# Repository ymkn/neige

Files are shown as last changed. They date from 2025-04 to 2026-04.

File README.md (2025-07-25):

# Neige

A compact 3-rows 30% keyboard with 12-column row staggered layout in 12.75u width.

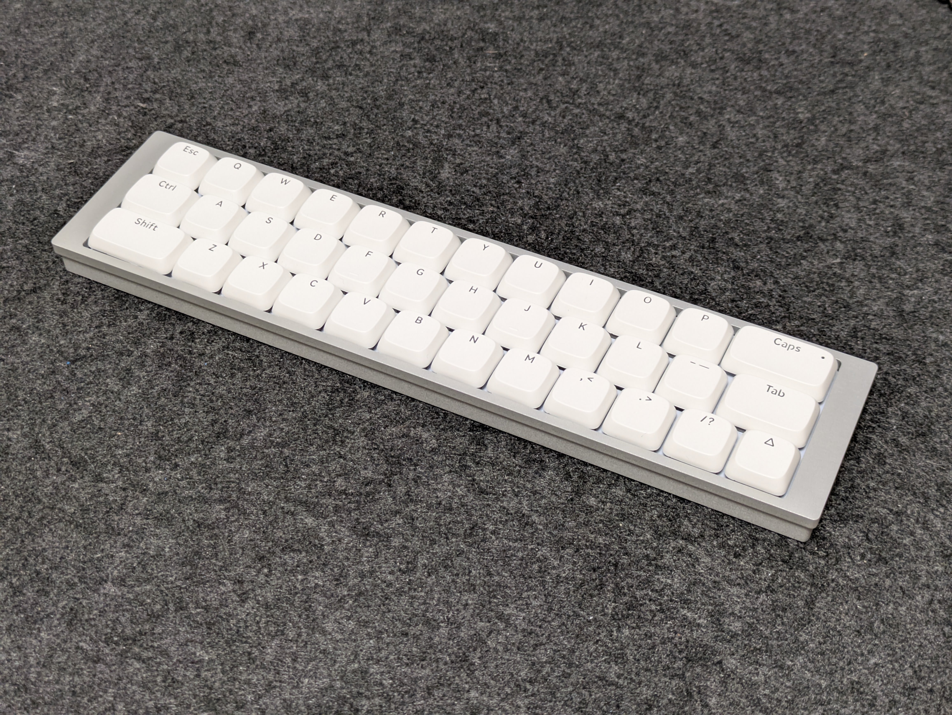
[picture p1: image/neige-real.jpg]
Neige real image


## Default Layout

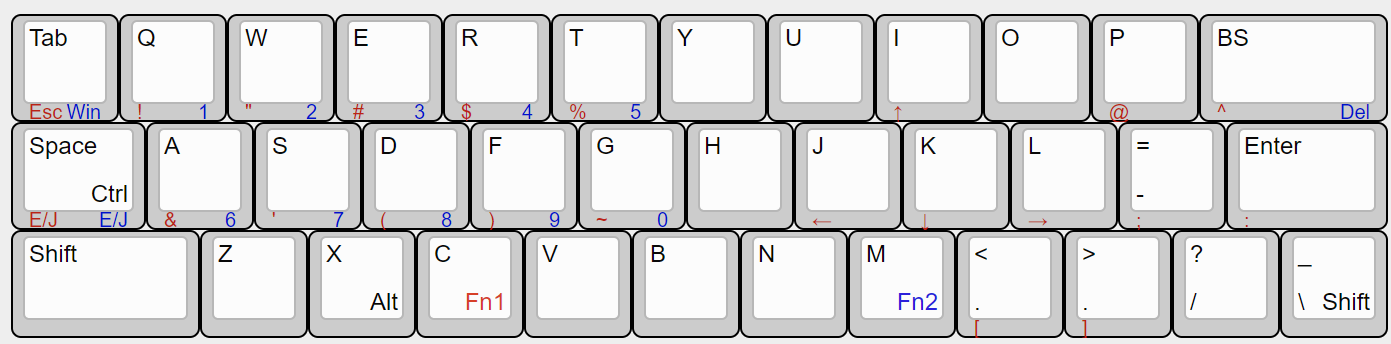
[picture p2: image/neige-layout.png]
Neige layouts


You can also customize the layout using [Vial](https://get.vial.today/).

## Build Guide

See [Build Guide](https://ymkn.github.io/buildguide/neige.html).

## License

This project is licensed under the MIT License, see the [LICENSE file](LICENSE) for details.

However, this does not apply to logo data (image files, KiCAD footprints, etc.) included in the resources of this project.

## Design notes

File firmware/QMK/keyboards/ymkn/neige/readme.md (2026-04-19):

# neige

neige - A compact 30% keyboard with 3-rows and 12-columns row staggered layout in 12.75u width.

* Keyboard Maintainer: [ymkn](https://github.com/ymkn)

Make example for this keyboard (after setting up your build environment):

    make ymkn/neige:vial

Flashing example for this keyboard:

1. Install and open [QMK Toolbox](https://qmk.fm/toolbox).
2. Disconnect the keyboard from the computer.
3. Hold the top-left key while connecting the USB cable, or hold the BOOT button on the back of the PCB while connecting the USB cable.
4. Confirm that QMK Toolbox shows `STM32 DFU device connected (WinUSB): STMicroelectronics STM32 BOOTLOADER`.
5. Click `Open` and select the compiled firmware file.
6. Click `Flash` and wait for the process to finish.
7. When QMK Toolbox shows `Flash complete`, the firmware update is complete.

This keyboard supports [Vial](https://get.vial.today/) configurator.

## Bootloader

Enter the bootloader in 2 ways:

* **Key on plug-in**: Hold the top-left key while connecting the keyboard to USB.
* **BOOT button**: Hold the BOOT button on the back of the PCB while connecting the keyboard to USB.

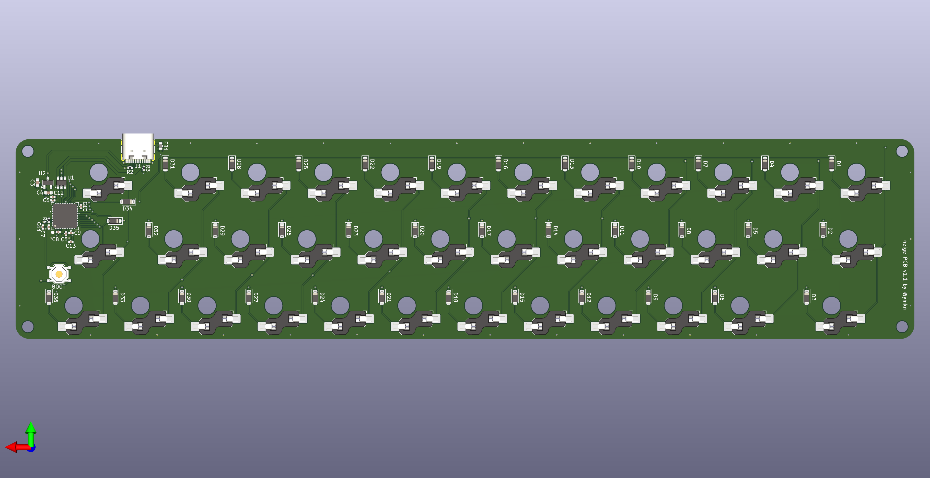
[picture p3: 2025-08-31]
KiCAD/PCB/production/Neige_PCB.png

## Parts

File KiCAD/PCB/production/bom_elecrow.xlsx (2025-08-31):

*Reference | *Manufacturer Part number | *QTY | *Original | Description | Purchase Link
BTN_BOOT1 | TS-1187A-B-A-B | 1 | N | No Without Bracket 50mA 5.1mm 100,000 Cycles 1.6N 12V 5.1mm 1.5mm Round Button Surface Mount,Vertical SPST SMD Tactile Switches ROHS | https://lcsc.com/product-detail/Tactile-Switches_XKB-Connectivity-TS-1187A-B-A-B_C318884.html
C9 | CL05B103KB5NNNC | 1 | N | 10nF 50V X7R ±10% 0402 Multilayer Ceramic Capacitors MLCC - SMD/SMT ROHS | https://lcsc.com/product-detail/Multilayer-Ceramic-Capacitors-MLCC-SMD-SMT_Samsung-Electro-Mechanics-CL05B103KB5NNNC_C15195.html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
C10, C5, C6, C7, C8 | CL05B104KO5NNNC | 6 | N | 16V 100nF X7R ±10% 0402 Multilayer Ceramic Capacitors MLCC - SMD/SMT ROHS | https://lcsc.com/product-detail/Multilayer-Ceramic-Capacitors-MLCC-SMD-SMT_Samsung-Electro-Mechanics-CL05B104KO5NNNC_C1525.html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
C3, C4 | CL10A106KP8NNNC | 2 | N | 10V 10uF X5R ±10% 0603 Multilayer Ceramic Capacitors MLCC - SMD/SMT ROHS | https://lcsc.com/product-detail/Multilayer-Ceramic-Capacitors-MLCC-SMD-SMT_Samsung-Electro-Mechanics-CL10A106KP8NNNC_C19702.html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
C11, C12 | CL05A475MP5NRNC | 2 | N | 10V 4.7uF X5R ±20% 0402 Multilayer Ceramic Capacitors MLCC - SMD/SMT ROHS | https://lcsc.com/product-detail/Multilayer-Ceramic-Capacitors-MLCC-SMD-SMT_Samsung-Electro-Mechanics-CL05A475MP5NRNC_C23733.html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
C13 | CL05A105KA5NQNC | 1 | N | 25V 1uF X5R ±10% 0402 Multilayer Ceramic Capacitors MLCC - SMD/SMT ROHS | https://lcsc.com/product-detail/Multilayer-Ceramic-Capacitors-MLCC-SMD-SMT_Samsung-Electro-Mechanics-CL05A105KA5NQNC_C52923.html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
D1 - D36 | 1N4148W | 36 | N | 75V Independent 1V@50mA 4ns 150mA SOD-123 Switching Diodes ROHS | https://lcsc.com/product-detail/Switching-Diodes_ST-Semtech-1N4148W_C81598.html?s_z=n_C81598
FB1 | CBM160808U600T | 1 | N | ±25% 60Ω@100MHz 0603 Ferrite Beads ROHS | https://lcsc.com/product-detail/Ferrite-Beads_FH-Guangdong-Fenghua-Advanced-Tech-CBM160808U600T_C394426.html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
J1 | TYPE-C 16PIN 2MD(073) | 1 | N | 3A USB 3.1 1 Surface Mount, Right Angle 16P Female -25℃~+85℃ Type-C SMD USB Connectors ROHS | https://lcsc.com/product-detail/USB-Connectors_SHOU-HAN-TYPE-C-16PIN-2MD-3_C2765186.html?s_z=n_C2765186
R2, R3 | 0402WGF5101TCE | 2 | N | 62.5mW Thick Film Resistor 50V ±100ppm/℃ ±1% 5.1kΩ 0402 Chip Resistor - Surface Mount ROHS | https://lcsc.com/product-detail/Chip-Resistor-Surface-Mount_UNI-ROYAL-Uniroyal-Elec-0402WGF5101TCE_C25905.html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
R4 | 0402WGF1002TCE | 1 | N | 62.5mW Thick Film Resistor 50V ±100ppm/℃ ±1% 10kΩ 0402 Chip Resistor - Surface Mount ROHS | https://lcsc.com/product-detail/Chip-Resistor-Surface-Mount_UNI-ROYAL-Uniroyal-Elec-0402WGF1002TCE_C25744.html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
SW1 - SW36 | CPG135001S30 | 36 | N | SMD Mechanical Keyboard Shaft ROHS | https://www.kailhswitch.com/mechanical-keyboard-switches/box-switches/choc-type-hot-swap-socket.html
U1 | USBLC6-2SC6 | 1 | N | 5A 17V 6V Unidirectional 5.25V SOT-23-6 ESD and Surge Protection (TVS/ESD) ROHS | https://lcsc.com/product-detail/ESD-and-Surge-Protection-TVS-ESD_STMicroelectronics-USBLC6-2SC6_C7519.html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
U2 | XC6206P332MR-G | 1 | N | 200mA Fixed 3.3V Positive 6V SOT-23-3L Voltage Regulators - Linear, Low Drop Out (LDO) Regulators ROHS | https://lcsc.com/product-detail/Voltage-Regulators-Linear-Low-Drop-Out-LDO-Regulators_Torex-Semicon-XC6206P332MR-G_C5446.html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
U3 | STM32F072CBU6 | 1 | Y | ARM-M0 48MHz UFQFPN-48(7x7) Microcontrollers (MCU/MPU/SOC) ROHS | https://lcsc.com/product-detail/Microcontrollers-MCU-MPU-SOC_STMicroelectronics-STM32F072CBU6_C92504.html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
Declare：
All ICs will be original even you selected Not original required.
Original: Y means must use the original brand model, N means that you can accept the substitutes with similar spec

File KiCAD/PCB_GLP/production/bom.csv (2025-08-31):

Designator | Footprint | Quantity | Value | LCSC Part #
BTN_BOOT1 | SW_Push_1P1T_XKB_TS-1187A | 1 | SW_Push | C318884
C10, C5, C6, C7, C8 | 0402 | 5 | 100nF | C1525
C11, C12 | 0402 | 2 | 4.7uF | C23733
C13 | 0402 | 1 | 1uF | C52923
C3, C4 | 0603 | 2 | 10uF | C19702
C9 | 0402 | 1 | 10nF | C15195
D1, D10, D11, D12, D13, D14, D15, D16, D17, D18, D19, D2, D20, D21, D22, D23, D24, D25, D26, D27, D28, D29, D3, D30, D31, D32, D33, D34, D35, D36, D4, D5, D6, D7, D8, D9 | D_SOD-123 | 36 | 1N4148W | C81598
FB1 | 0603 | 1 | FerriteBead | C394426
J1 | USB_C_Receptacle_HRO_TYPE-C-31-M-12 | 1 | TYPE-C 16PIN 2MD(073) | C2765186
R2, R3 | 0402 | 2 | 5.1K | C25905
R4 | 0402 | 1 | 10K | C25744
SW1, SW10, SW11, SW12, SW13, SW14, SW15, SW16, SW17, SW18, SW19, SW20, SW21, SW22, SW23, SW24, SW25, SW26, SW27, SW28, SW29, SW30, SW31, SW32, SW33, SW36, SW4, SW5, SW6, SW7, SW8, SW9 | SW_MX_GLP3_1u | 32 | SW_Push | C41430893
SW2 | SW_MX_GLP3_1.25u | 1 | SW_Push | C41430893
SW3, SW34 | SW_MX_GLP3_1.75u | 2 | SW_Push | C41430893
SW35 | SW_MX_GLP3_1.5u | 1 | SW_Push | C41430893
U1 | SOT-23-6 | 1 | USBLC6-2SC6 | C7519
U2 | SOT-23-3 | 1 | XC6206P332MR | C5446
U3 | UFQFPN48-7x7mm | 1 | STM32F072CBU6 | C92504

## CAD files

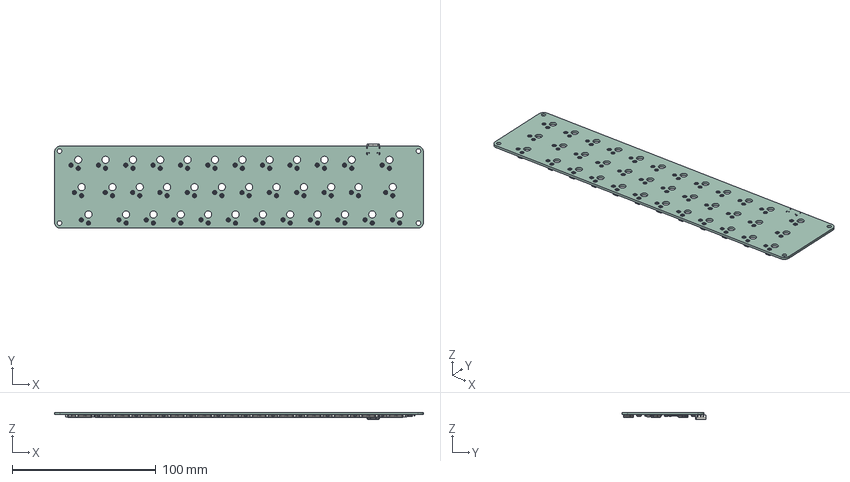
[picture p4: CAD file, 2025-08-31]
KiCAD/PCB/production/Neige_PCB.step
257.0 x 58.7 x 4.96 mm
HS_Kailh_Choc v4 x 36
D_SOD_123 x 36
R_0402_1005Metric x 3
C_0402_1005Metric x 9
L_0603_1608Metric
SOT-23-3
QFN-48-1EP_7x7mm_Pitch0.5mm
USB_C_Receptacle_16P_TopMnt_Horizontal_GCT_USB4105-xx-A
SOT_23_6
C_0603_1608Metric x 2
SW_SPST_TL3342
Neige_PCB_PCB

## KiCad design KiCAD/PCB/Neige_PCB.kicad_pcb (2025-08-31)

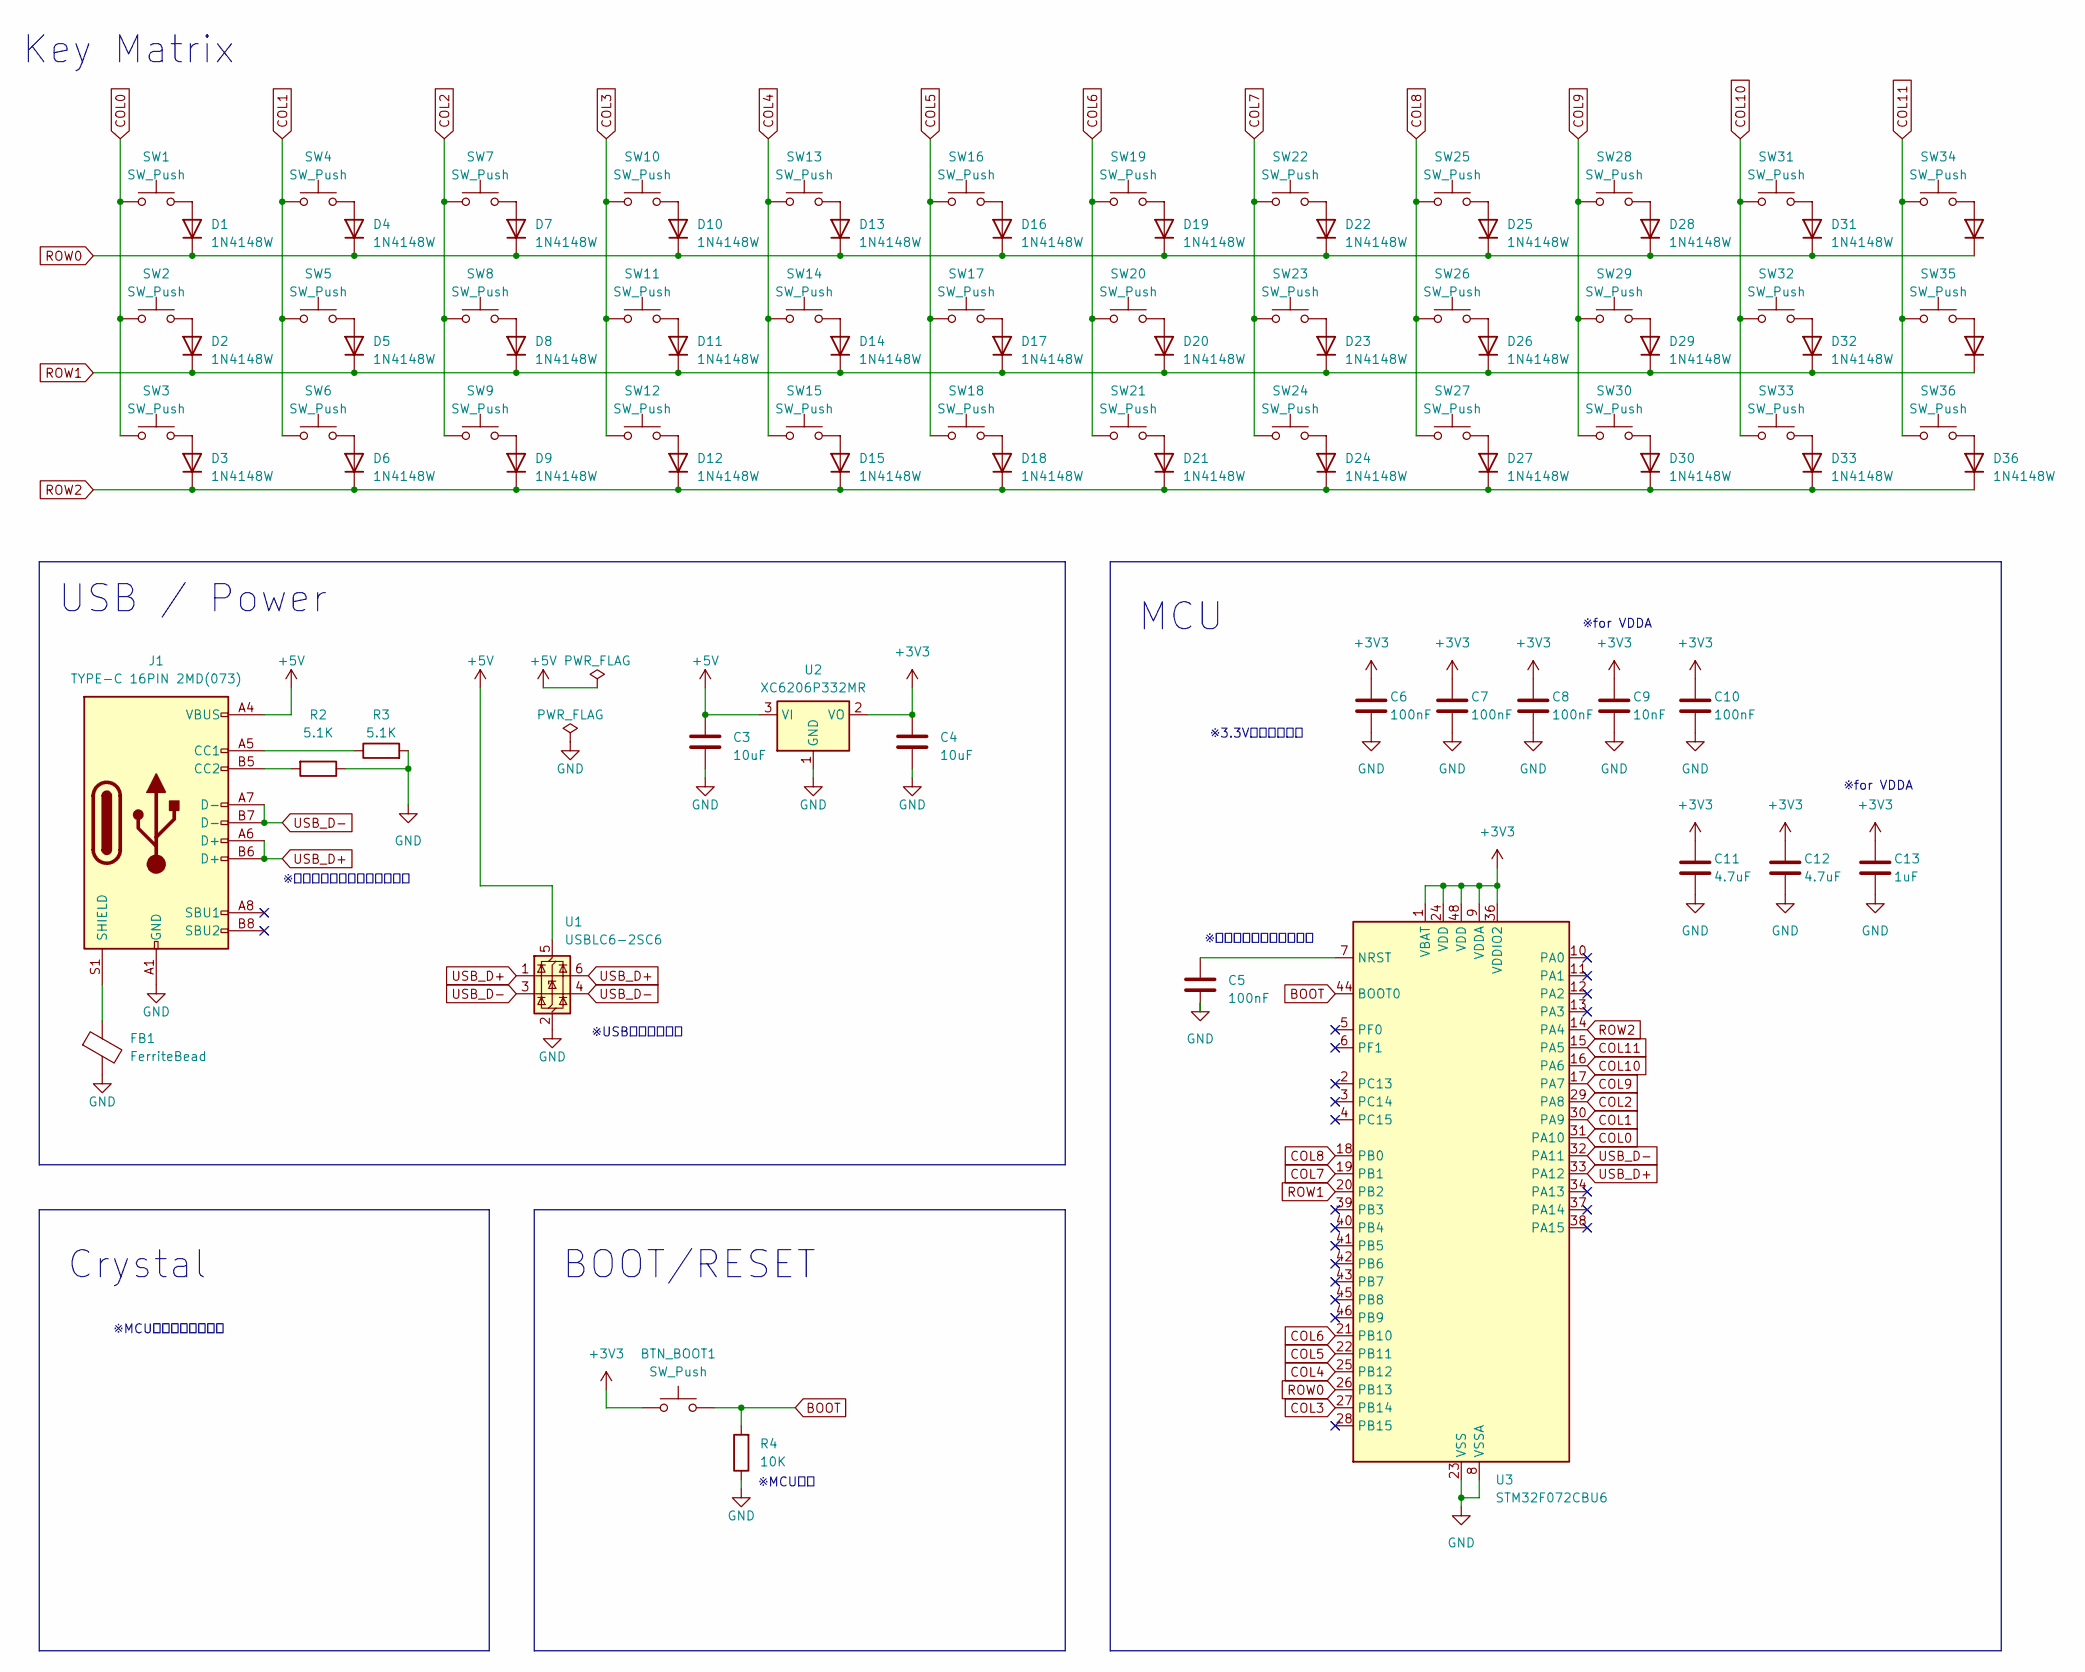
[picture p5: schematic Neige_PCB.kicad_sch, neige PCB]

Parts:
BTN_BOOT1: SW_Push; SW_Push_1P1T_XKB_TS-1187A; JLCPCB Part # C318884
C3, C4: 10uF; C_0603_1608Metric; JLCPCB Part # C19702
C5, C6, C7, C8, C10: 100nF; C_0402_1005Metric; JLCPCB Part # C1525
C9: 10nF; C_0402_1005Metric; JLCPCB Part # C15195
C11, C12: 4.7uF; C_0402_1005Metric; JLCPCB Part # C23733
C13: 1uF; C_0402_1005Metric; JLCPCB Part # C52923
D1, D2, D3, D4, D5, D6, D7, D8, D9, D10, D11, D12, D13, D14, D15, D16, D17, D18, D19, D20, D21, D22, D23, D24, D25, D26, D27, D28, D29, D30, D31, D32, D33, D34, D35, D36: 1N4148W; D_SOD-123; LCSC Parts # C81598
FB1: FerriteBead; L_0603_1608Metric; JLCPCB Part # C394426
J1: TYPE-C 16PIN 2MD(073); USB_C_Receptacle_HRO_TYPE-C-31-M-12; JLCPCB Part # C2765186
R2, R3: 5.1K; R_0402_1005Metric; JLCPCB Part # C25905
R4: 10K; R_0402_1005Metric; JLCPCB Part # C25744
SW1, SW4, SW5, SW6, SW7, SW8, SW9, SW10, SW11, SW12, SW13, SW14, SW15, SW16, SW17, SW18, SW19, SW20, SW21, SW22, SW23, SW24, SW25, SW26, SW27, SW28, SW29, SW30, SW31, SW32, SW33, SW36: SW_Push; SW_choc_v2_1u; LCSC Parts # C18212911
SW2: SW_Push; SW_choc_v2_1.25u; LCSC Parts # C18212911
SW3, SW34: SW_Push; SW_choc_v2_1.75u; LCSC Parts # C18212911
SW35: SW_Push; SW_choc_v2_1.5u; LCSC Parts # C18212911
U1: USBLC6-2SC6; SOT-23-6; JLCPCB Part # C7519
U2: XC6206P332MR; SOT-23-3; JLCPCB Part # C5446
U3: STM32F072CBU6; UFQFPN48-7x7mm; JLCPCB Part # C92504

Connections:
+3V3: BTN_BOOT1.1, C4.1, C6.1, C7.1, C8.1, C9.1, C10.1, C11.1, C12.1, C13.1, U2.2 (VO), U3.1 (VBAT), U3.9 (VDDA), U3.24 (VDD), U3.36 (VDDIO2), U3.48 (VDD)
+5V: C3.1, J1.A4 (VBUS), J1.A9 (VBUS), J1.B4 (VBUS), J1.B9 (VBUS), U1.5 (VBUS), U2.3 (VI)
BOOT: BTN_BOOT1.2, R4.2, U3.44 (BOOT0)
COL0: SW1.1, SW2.1, SW3.1, U3.31 (PA10)
COL1: SW4.1, SW5.1, SW6.1, U3.30 (PA9)
COL2: SW7.1, SW8.1, SW9.1, U3.29 (PA8)
COL3: SW10.1, SW11.1, SW12.1, U3.27 (PB14)
COL4: SW13.1, SW14.1, SW15.1, U3.25 (PB12)
COL5: SW16.1, SW17.1, SW18.1, U3.22 (PB11)
COL6: SW19.1, SW20.1, SW21.1, U3.21 (PB10)
COL7: SW22.1, SW23.1, SW24.1, U3.19 (PB1)
COL8: SW25.1, SW26.1, SW27.1, U3.18 (PB0)
COL9: SW28.1, SW29.1, SW30.1, U3.17 (PA7)
COL10: SW31.1, SW32.1, SW33.1, U3.16 (PA6)
COL11: SW34.1, SW35.1, SW36.1, U3.15 (PA5)
GND: C3.2, C4.2, C5.2, C6.2, C7.2, C8.2, C9.2, C10.2, C11.2, C12.2, C13.2, FB1.2, J1.A1 (GND), J1.A12 (GND), J1.B1 (GND), J1.B12 (GND), R2.1, R3.2, R4.1, U1.2 (GND), U2.1 (GND), U3.8 (VSSA), U3.23 (VSS), U3.35 (VSS), U3.47 (VSS), U3.49 (VSS)
unnamed: D1.2 (A), SW1.2
unnamed: D2.2 (A), SW2.2
unnamed: D3.2 (A), SW3.2
unnamed: D4.2 (A), SW4.2
unnamed: D5.2 (A), SW5.2
unnamed: D6.2 (A), SW6.2
unnamed: D7.2 (A), SW7.2
unnamed: D8.2 (A), SW8.2
unnamed: D9.2 (A), SW9.2
unnamed: D10.2 (A), SW10.2
unnamed: D11.2 (A), SW11.2
unnamed: D12.2 (A), SW12.2
unnamed: D13.2 (A), SW13.2
unnamed: D14.2 (A), SW14.2
unnamed: D15.2 (A), SW15.2
unnamed: D16.2 (A), SW16.2
unnamed: D17.2 (A), SW17.2
unnamed: D18.2 (A), SW18.2
unnamed: D19.2 (A), SW19.2
unnamed: D20.2 (A), SW20.2
unnamed: D21.2 (A), SW21.2
unnamed: D22.2 (A), SW22.2
unnamed: D23.2 (A), SW23.2
unnamed: D24.2 (A), SW24.2
unnamed: D25.2 (A), SW25.2
unnamed: D26.2 (A), SW26.2
unnamed: D27.2 (A), SW27.2
unnamed: D28.2 (A), SW28.2
unnamed: D29.2 (A), SW29.2
unnamed: D30.2 (A), SW30.2
unnamed: D31.2 (A), SW31.2
unnamed: D32.2 (A), SW32.2
unnamed: D33.2 (A), SW33.2
unnamed: D34.2 (A), SW34.2
unnamed: D35.2 (A), SW35.2
unnamed: D36.2 (A), SW36.2
unnamed: J1.A5 (CC1), R3.1
unnamed: J1.B5 (CC2), R2.2
unnamed: FB1.1, J1.S1 (SHIELD)
unnamed: C5.1, U3.7 (NRST)
ROW0: D1.1 (K), D4.1 (K), D7.1 (K), D10.1 (K), D13.1 (K), D16.1 (K), D19.1 (K), D22.1 (K), D25.1 (K), D28.1 (K), D31.1 (K), D34.1 (K), U3.26 (PB13)
ROW1: D2.1 (K), D5.1 (K), D8.1 (K), D11.1 (K), D14.1 (K), D17.1 (K), D20.1 (K), D23.1 (K), D26.1 (K), D29.1 (K), D32.1 (K), D35.1 (K), U3.20 (PB2)
ROW2: D3.1 (K), D6.1 (K), D9.1 (K), D12.1 (K), D15.1 (K), D18.1 (K), D21.1 (K), D24.1 (K), D27.1 (K), D30.1 (K), D33.1 (K), D36.1 (K), U3.14 (PA4)
USB_D+: J1.A6 (D+), J1.B6 (D+), U1.1 (I/O1), U1.6 (I/O1), U3.33 (PA12)
USB_D-: J1.A7 (D-), J1.B7 (D-), U1.3 (I/O2), U1.4 (I/O2), U3.32 (PA11)

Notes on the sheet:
※MCU内蔵クロック使用
Crystal
MCU
Key Matrix
※for VDDA
※MCU近傍
※USBコネクタ近傍
BOOT/RESET
※3.3V電源ピン近傍
※差動信号、配線長さ合わせる
USB / Power
※リセットボタン実装無し

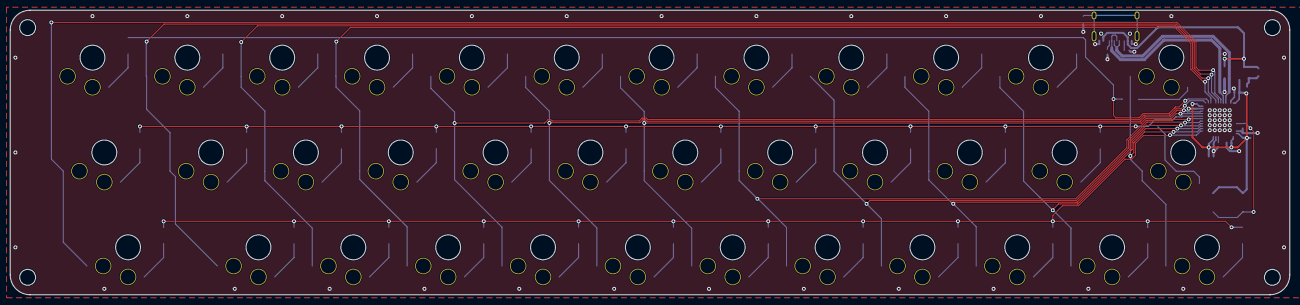
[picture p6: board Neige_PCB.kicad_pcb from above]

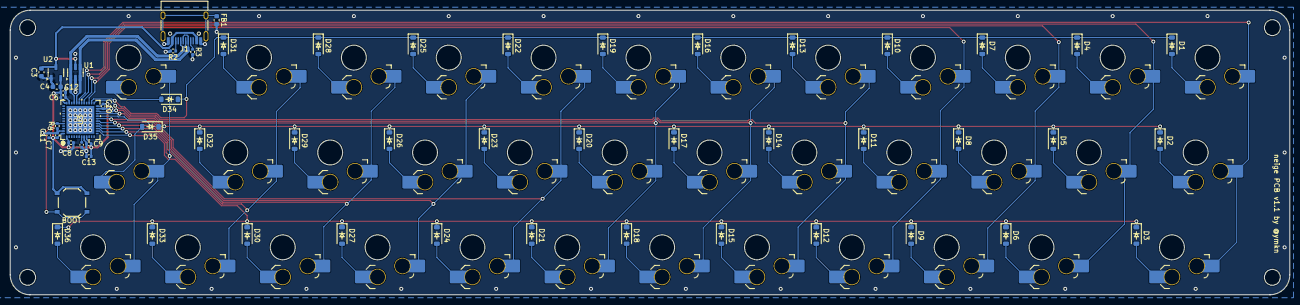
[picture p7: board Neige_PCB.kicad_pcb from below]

Board: 2 copper layers, 257.0 x 57.1 mm, 92 parts (92 on the bottom side), 61 nets.

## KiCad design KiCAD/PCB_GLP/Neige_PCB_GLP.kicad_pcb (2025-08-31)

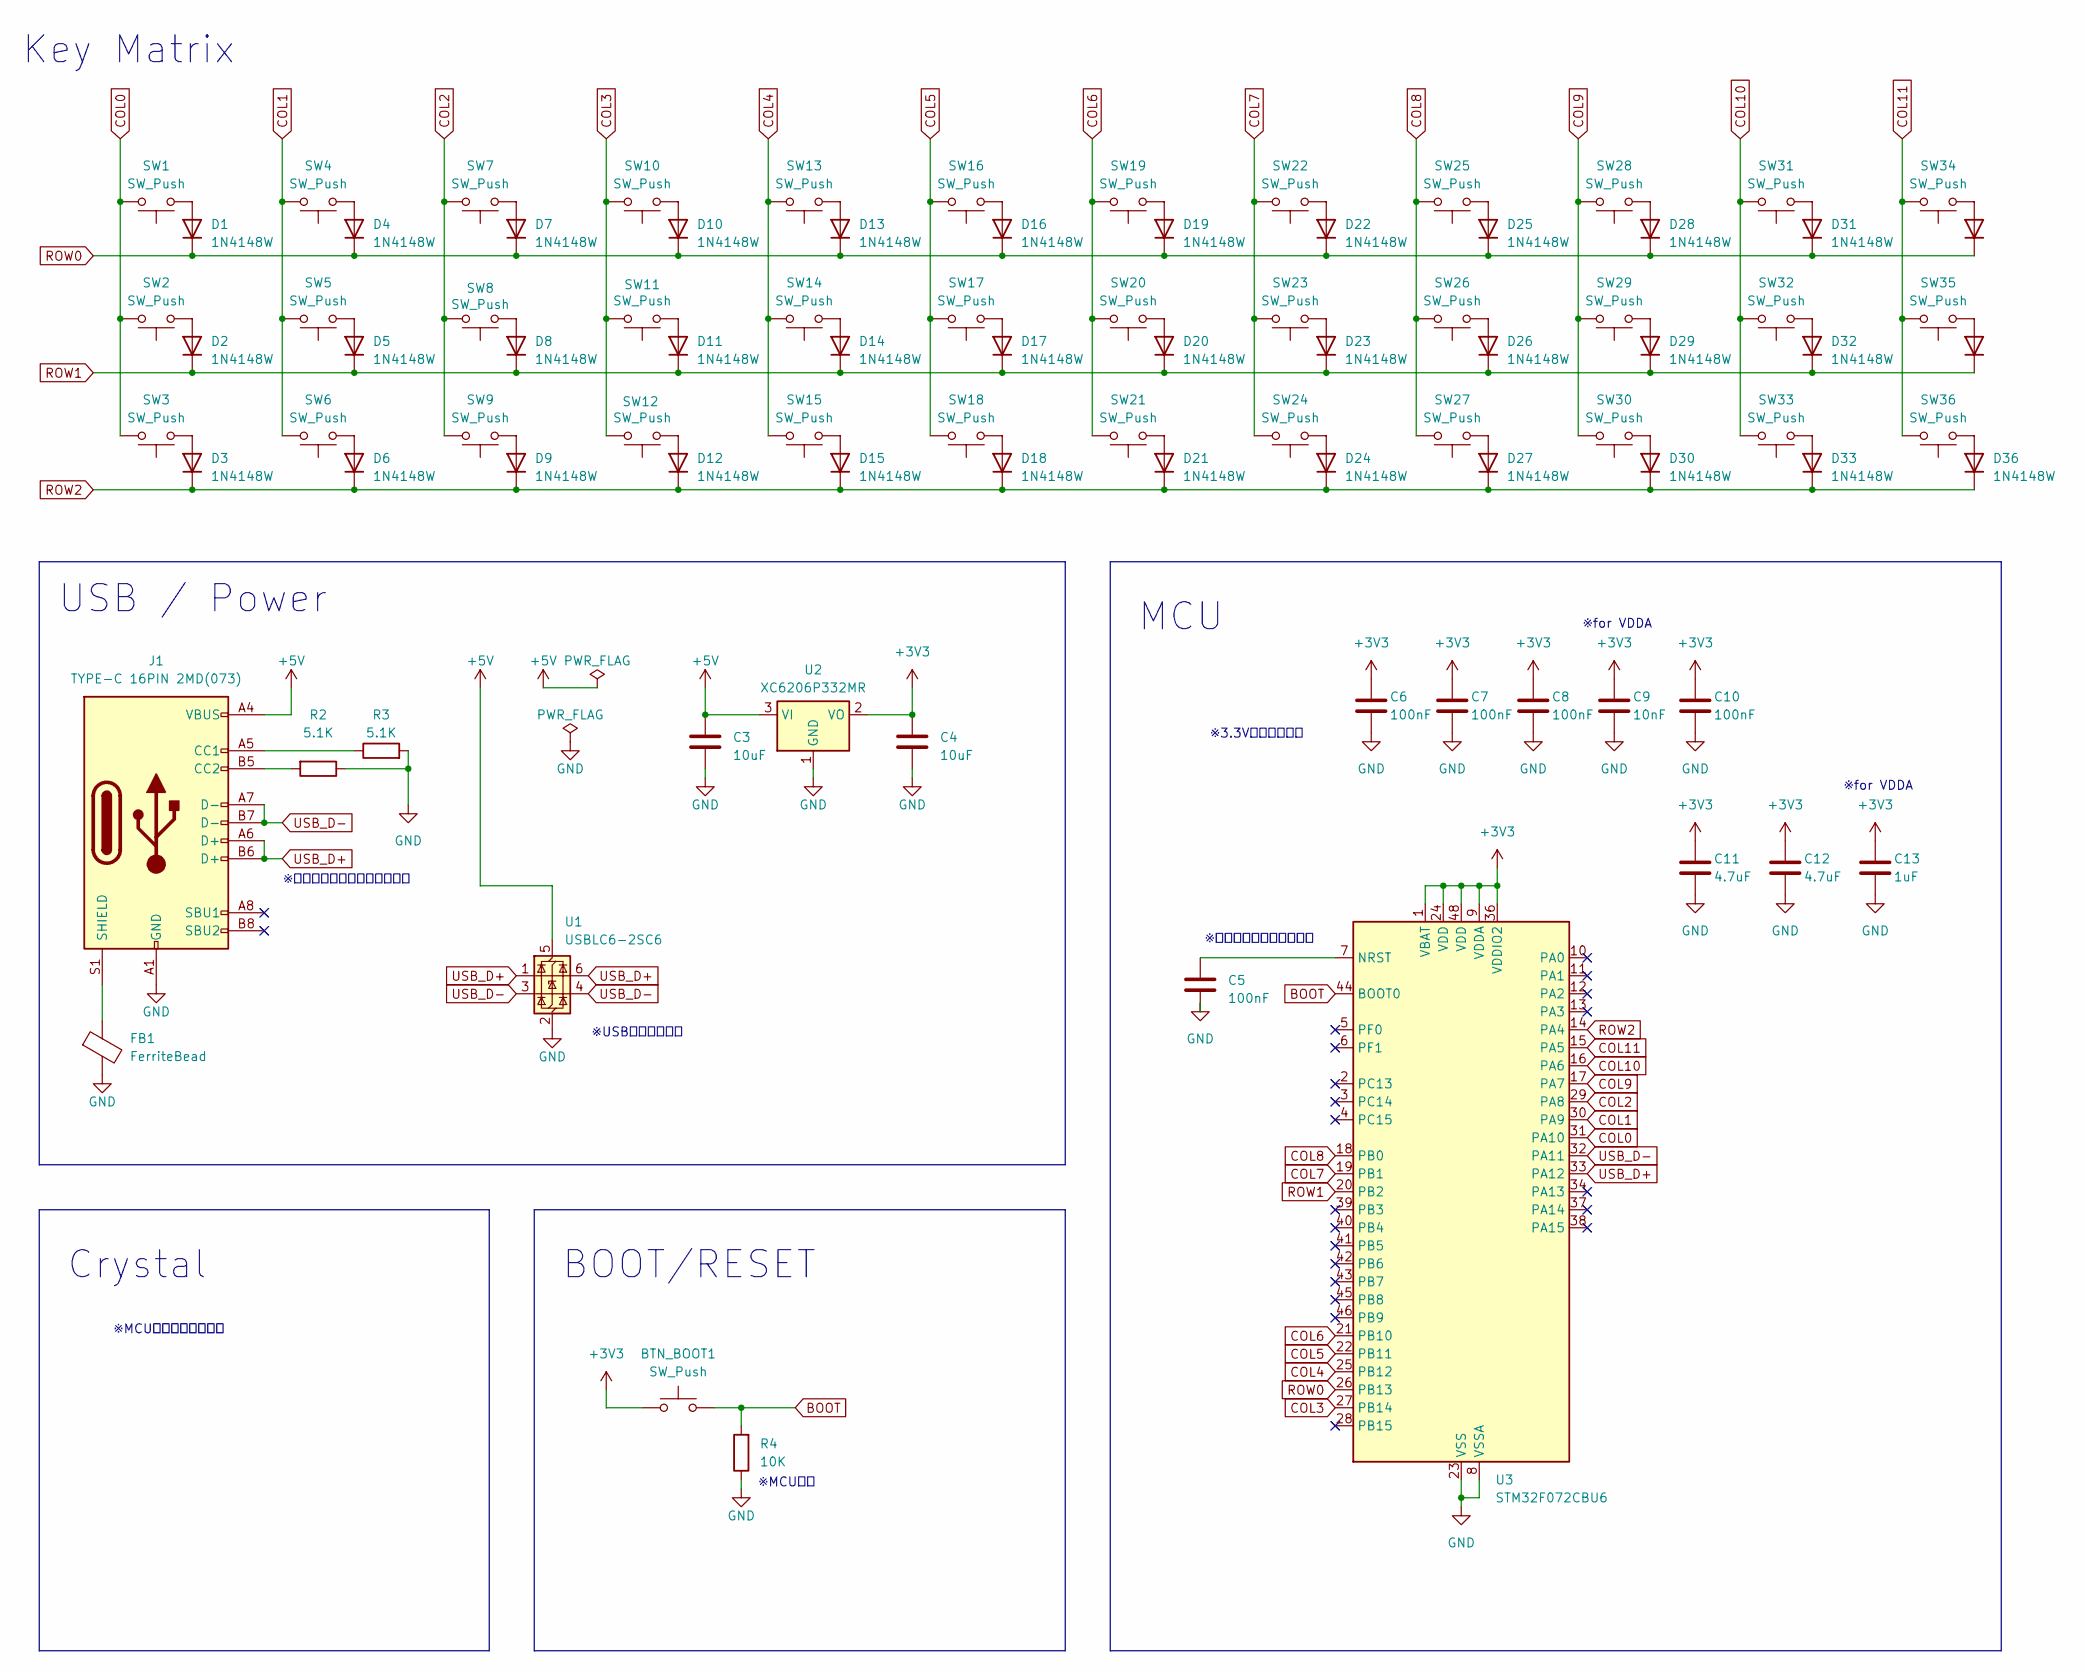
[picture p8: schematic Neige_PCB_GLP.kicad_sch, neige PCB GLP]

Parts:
BTN_BOOT1: SW_Push; SW_Push_1P1T_XKB_TS-1187A; JLCPCB Part # C318884
C3, C4: 10uF; C_0603_1608Metric; JLCPCB Part # C19702
C5, C6, C7, C8, C10: 100nF; C_0402_1005Metric; JLCPCB Part # C1525
C9: 10nF; C_0402_1005Metric; JLCPCB Part # C15195
C11, C12: 4.7uF; C_0402_1005Metric; JLCPCB Part # C23733
C13: 1uF; C_0402_1005Metric; JLCPCB Part # C52923
D1, D2, D3, D4, D5, D6, D7, D8, D9, D10, D11, D12, D13, D14, D15, D16, D17, D18, D19, D20, D21, D22, D23, D24, D25, D26, D27, D28, D29, D30, D31, D32, D33, D34, D35, D36: 1N4148W; D_SOD-123; LCSC Parts # C81598
FB1: FerriteBead; L_0603_1608Metric; JLCPCB Part # C394426
J1: TYPE-C 16PIN 2MD(073); USB_C_Receptacle_HRO_TYPE-C-31-M-12; JLCPCB Part # C2765186
R2, R3: 5.1K; R_0402_1005Metric; JLCPCB Part # C25905
R4: 10K; R_0402_1005Metric; JLCPCB Part # C25744
SW1, SW4, SW5, SW6, SW7, SW8, SW9, SW10, SW11, SW12, SW13, SW14, SW15, SW16, SW17, SW18, SW19, SW20, SW21, SW22, SW23, SW24, SW25, SW26, SW27, SW28, SW29, SW30, SW31, SW32, SW33, SW36: SW_Push; SW_MX_GLP3_1u; LCSC Parts # C18212911
SW2: SW_Push; SW_MX_GLP3_1.25u; LCSC Parts # C18212911
SW3, SW34: SW_Push; SW_MX_GLP3_1.75u; LCSC Parts # C18212911
SW35: SW_Push; SW_MX_GLP3_1.5u; LCSC Parts # C18212911
U1: USBLC6-2SC6; SOT-23-6; JLCPCB Part # C7519
U2: XC6206P332MR; SOT-23-3; JLCPCB Part # C5446
U3: STM32F072CBU6; UFQFPN48-7x7mm; JLCPCB Part # C92504

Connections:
+3V3: BTN_BOOT1.1, C4.1, C6.1, C7.1, C8.1, C9.1, C10.1, C11.1, C12.1, C13.1, U2.2 (VO), U3.1 (VBAT), U3.9 (VDDA), U3.24 (VDD), U3.36 (VDDIO2), U3.48 (VDD)
+5V: C3.1, J1.A4 (VBUS), J1.A9 (VBUS), J1.B4 (VBUS), J1.B9 (VBUS), U1.5 (VBUS), U2.3 (VI)
BOOT: BTN_BOOT1.2, R4.2, U3.44 (BOOT0)
COL0: SW1.2, SW2.2, SW3.2, U3.31 (PA10)
COL1: SW4.2, SW5.2, SW6.2, U3.30 (PA9)
COL2: SW7.2, SW8.2, SW9.2, U3.29 (PA8)
COL3: SW10.2, SW11.2, SW12.2, U3.27 (PB14)
COL4: SW13.2, SW14.2, SW15.2, U3.25 (PB12)
COL5: SW16.2, SW17.2, SW18.2, U3.22 (PB11)
COL6: SW19.2, SW20.2, SW21.2, U3.21 (PB10)
COL7: SW22.2, SW23.2, SW24.2, U3.19 (PB1)
COL8: SW25.2, SW26.2, SW27.2, U3.18 (PB0)
COL9: SW28.2, SW29.2, SW30.2, U3.17 (PA7)
COL10: SW31.2, SW32.2, SW33.2, U3.16 (PA6)
COL11: SW34.2, SW35.2, SW36.2, U3.15 (PA5)
GND: C3.2, C4.2, C5.2, C6.2, C7.2, C8.2, C9.2, C10.2, C11.2, C12.2, C13.2, FB1.2, J1.A1 (GND), J1.A12 (GND), J1.B1 (GND), J1.B12 (GND), R2.1, R3.2, R4.1, U1.2 (GND), U2.1 (GND), U3.8 (VSSA), U3.23 (VSS), U3.35 (VSS), U3.47 (VSS), U3.49 (VSS)
unnamed: D1.2 (A), SW1.1
unnamed: D2.2 (A), SW2.1
unnamed: D3.2 (A), SW3.1
unnamed: D4.2 (A), SW4.1
unnamed: D5.2 (A), SW5.1
unnamed: D6.2 (A), SW6.1
unnamed: D7.2 (A), SW7.1
unnamed: D8.2 (A), SW8.1
unnamed: D9.2 (A), SW9.1
unnamed: D10.2 (A), SW10.1
unnamed: D11.2 (A), SW11.1
unnamed: D12.2 (A), SW12.1
unnamed: D13.2 (A), SW13.1
unnamed: D14.2 (A), SW14.1
unnamed: D15.2 (A), SW15.1
unnamed: D16.2 (A), SW16.1
unnamed: D17.2 (A), SW17.1
unnamed: D18.2 (A), SW18.1
unnamed: D19.2 (A), SW19.1
unnamed: D20.2 (A), SW20.1
unnamed: D21.2 (A), SW21.1
unnamed: D22.2 (A), SW22.1
unnamed: D23.2 (A), SW23.1
unnamed: D24.2 (A), SW24.1
unnamed: D25.2 (A), SW25.1
unnamed: D26.2 (A), SW26.1
unnamed: D27.2 (A), SW27.1
unnamed: D28.2 (A), SW28.1
unnamed: D29.2 (A), SW29.1
unnamed: D30.2 (A), SW30.1
unnamed: D31.2 (A), SW31.1
unnamed: D32.2 (A), SW32.1
unnamed: D33.2 (A), SW33.1
unnamed: D34.2 (A), SW34.1
unnamed: D35.2 (A), SW35.1
unnamed: D36.2 (A), SW36.1
unnamed: J1.A5 (CC1), R3.1
unnamed: J1.B5 (CC2), R2.2
unnamed: FB1.1, J1.S1 (SHIELD)
unnamed: C5.1, U3.7 (NRST)
ROW0: D1.1 (K), D4.1 (K), D7.1 (K), D10.1 (K), D13.1 (K), D16.1 (K), D19.1 (K), D22.1 (K), D25.1 (K), D28.1 (K), D31.1 (K), D34.1 (K), U3.26 (PB13)
ROW1: D2.1 (K), D5.1 (K), D8.1 (K), D11.1 (K), D14.1 (K), D17.1 (K), D20.1 (K), D23.1 (K), D26.1 (K), D29.1 (K), D32.1 (K), D35.1 (K), U3.20 (PB2)
ROW2: D3.1 (K), D6.1 (K), D9.1 (K), D12.1 (K), D15.1 (K), D18.1 (K), D21.1 (K), D24.1 (K), D27.1 (K), D30.1 (K), D33.1 (K), D36.1 (K), U3.14 (PA4)
USB_D+: J1.A6 (D+), J1.B6 (D+), U1.1 (I/O1), U1.6 (I/O1), U3.33 (PA12)
USB_D-: J1.A7 (D-), J1.B7 (D-), U1.3 (I/O2), U1.4 (I/O2), U3.32 (PA11)

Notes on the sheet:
※MCU内蔵クロック使用
Crystal
MCU
Key Matrix
※for VDDA
※MCU近傍
※USBコネクタ近傍
BOOT/RESET
※3.3V電源ピン近傍
※差動信号、配線長さ合わせる
USB / Power
※リセットボタン実装無し

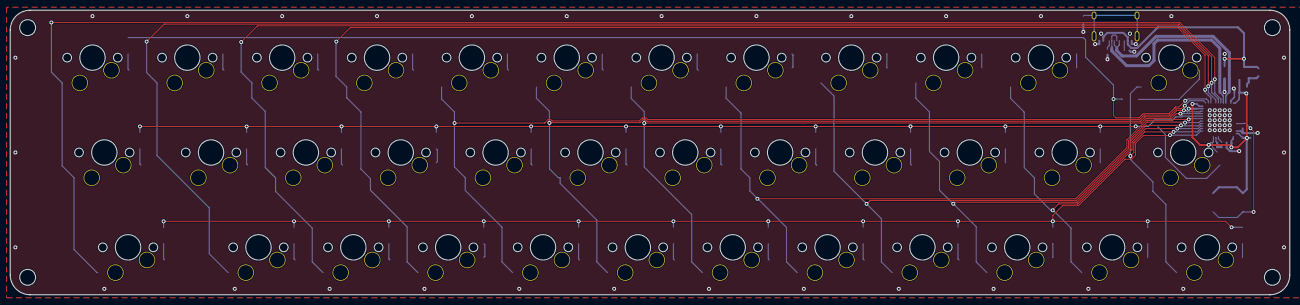
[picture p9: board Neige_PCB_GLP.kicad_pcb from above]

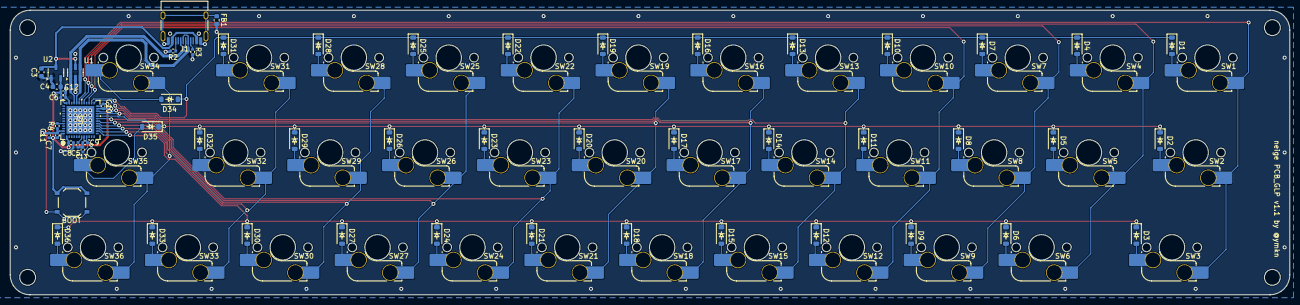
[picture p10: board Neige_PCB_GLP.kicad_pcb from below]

Board: 2 copper layers, 257.0 x 57.1 mm, 92 parts (92 on the bottom side), 61 nets.

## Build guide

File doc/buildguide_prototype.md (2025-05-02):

# Neige試作版ビルドガイド

## 1. 本書について

本書は[天キーVol.8](https://tenkey.connpass.com/event/349566/)で少量配布した自作キーボードNeigeキットの試作版ビルドガイドです。

試作品かつ難ありのため、経験者向けとし、簡潔な記載としています。

- 試作基板は設計ミスによりRP2040-Zeroの取り付け向きが本来意図と異なります。そのため必要な足の長さが本来よりも長く、最終的に作られる製品版ケースとの互換性がありません
- スイッチプレートにUSBコネクタとの干渉避け切り欠きがありません。が、1点目のミスの結果、USBコネクタ位置が下がり干渉しない状態になっています
- シルク印刷が開発コードのままになっています

## 2. 準備

### 2.1 内容物の確認

|番号|品目|数量|
|---|---|---|
|1|Neige スイッチプレート|1枚|
|2|Neige メイン基板|1枚|

### 2.2 別途用意が必要な部品

下記は本キットに含まれません。国内外の自作キーボード専門店や電子部品販売店などから別途調達してください。

|品目|数量|備考|
|---|---|---|
|Waveshare RP2040-Zero|1|互換品は部品配置が異なる場合があり、基板の切り欠きと干渉することがありますので利用にはご注意ください|
|1N4148W ダイオード|36|SOD-123パッケージを想定|
|Kailh Choc用スイッチソケット|36||
|Kailh Choc V2 Full POM互換スイッチ|36|Lofree Flow向けとして知られるスイッチ。元祖？Choc V2スイッチとは仕様が異なるため互換性はありません|
|MX互換キーキャップ|必要数|上記スイッチで利用可能なもの。キーピッチはフルサイズ（19.05mm）なので、高さ方向だけ注意|
|足用のスペーサーやネジ、ゴム足|4セット|お好みに応じて。足の高さは4mm以上必要です。基板のしなりを考慮して5mm程度にしておくと安心です

### 2.3 適合するキーキャップサイズ

下図の通りのキーキャップが必要です。

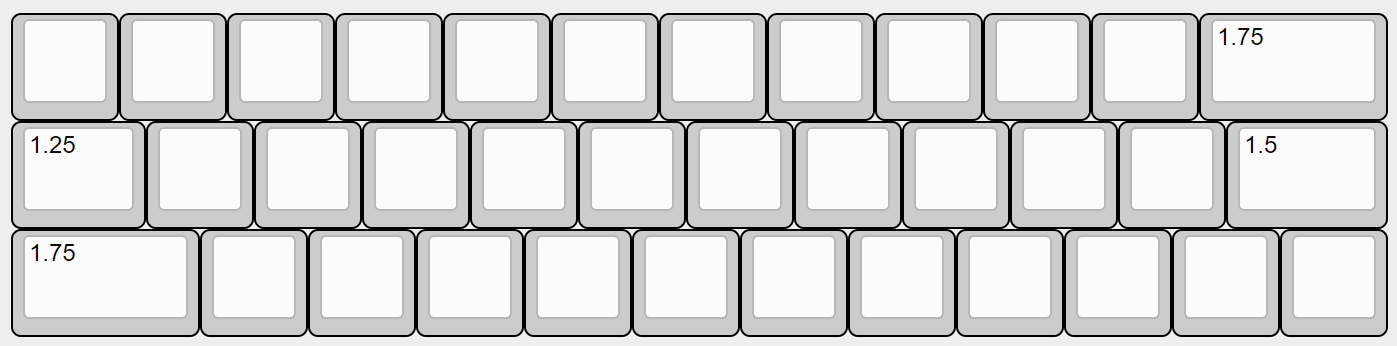
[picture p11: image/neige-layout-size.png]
レイアウト


## 3. 組み立て

### 3.1 RP2040-Zeroの動作確認とファームウェアの書き込み

下記からファームウェアを入手し、RP2040-Zeroに書き込んでください。

[https://github.com/ymkn/neige/releases/download/v0.1/ymkn_neige_vial.uf2](https://github.com/ymkn/neige/releases/download/v0.1/ymkn_neige_vial.uf2)

### 3.2 ダイオードとスイッチソケットのはんだ付け

基板裏面のシルク印刷に合わせてはんだ付けしてください。ソケット、ダイオードともに向きがありますので注意。

### 3.3 RP2040-Zeroのはんだ付け

ウラ面側にボタンが来る向き（1番ピンが右上）で、ウラ裏面側にはんだ付けをしてください。

> [!NOTE] 試作基板の設計ミスにより、本来意図と取り付け向きが異なります

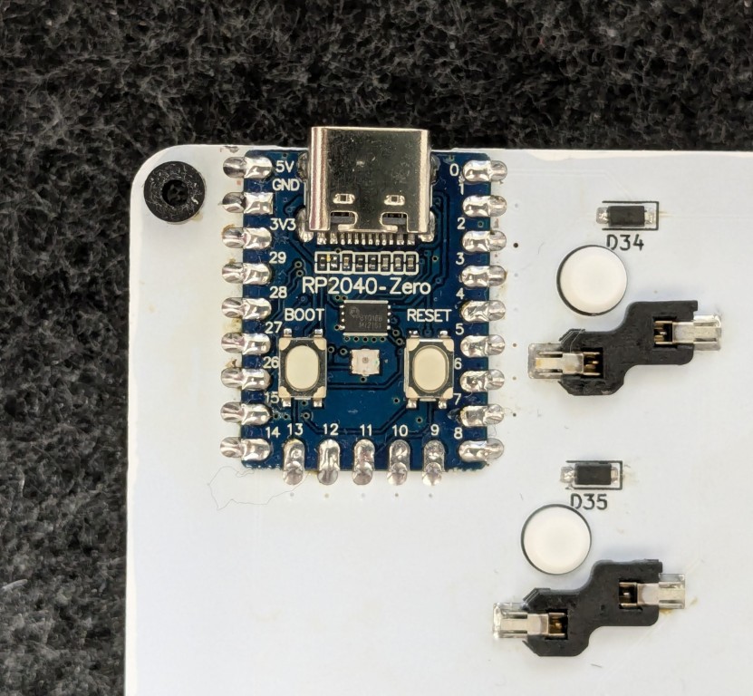
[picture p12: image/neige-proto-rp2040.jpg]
RP2040向き


### 3.4 スイッチとキーキャップの取り付け

スイッチプレートの横方向に若干の余裕を持たせている関係で、基板に挿す前だとスイッチの固定が甘く感じるかと思います。挿してしまえばしっかり固定されますので気にしないでください。

### 3.5 足の取り付け

脚についてはスペーサーやゴム足などで適当に対応してください。試作基板においては最低4mmちょいあれば十分かと思います（RP2040-Zeroのボタンが一番出っ張っている部分なので、そこに干渉しない長さを確保する）。

基板の四隅にマウント用の穴（直径3.2mm）がありますのでご活用ください。

### 3.6 基板の保護

ウラ面は接点がむき出しの状態ですので、金属製の机で使うとショートする可能性があります。気になる場合はマスキングテープなどで保護するか、ボトムプレートを作成してください。

## 4. 使用

### 4.1 動作確認

コンピュータとNeigeをUSBケーブルで接続し、キーボードとして認識され、文字が入力できることを確認してください。

### 4.2 初期設定とキーマップのカスタマイズ

キーマップのカスタマイズは[Vial](https://get.vial.today/)にて行えます。

初期キーマップで使う場合は下記からキーマップ定義をダウンロードし、アプリ版のVialにて`File > Load saved layout`から読み込んでください。これによりTapDanceの定義やQMK Settingsが復元され利用可能になります。

[https://github.com/ymkn/neige/releases/download/v0.1/neige.vil](https://github.com/ymkn/neige/releases/download/v0.1/neige.vil)

## 5. その他

### 5.1 ブートモードの入り方

ブートモードに入るには、USBケーブルを切断してから、左上のキー（Tabキー）を押しながらUSBケーブルを接続します。

もしくは、USBケーブルを接続した状態でドーターボード上のBOOTボタンを押しながらRESETボタンを押します。

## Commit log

2025-04-30 試作版ビルドガイドの追加
2025-05-02 vilファイルのロード手順を追加
2025-05-11 プロトタイプ版の寸法資料を追加
2025-06-13 submoduleの追加
2025-06-13 基板とファームウェア
    [Neige_PCB.kicad_pcb, Neige_PCB.kicad_sch, Neige_SwitchPlate.kicad_pcb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]
2025-07-29 デフォルトキーマップ変更
2025-07-29 デフォルトvilファイルの追加
2025-08-31 デフォルトキーマップの微修正
2025-08-31 パスコン見直し版
    [Neige_PCB.kicad_pcb, Neige_PCB.kicad_sch, Neige_PCB.step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]
2025-08-31 backup等除外
2025-08-31 Gateron LP 3.0版
    [Neige_PCB_GLP.kicad_pcb, Neige_PCB_GLP.kicad_sch, bom.csv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]
2025-08-31 寸法公開用SVGの追加
    [Neige_PCB.kicad_pcb, Neige_SwitchPlate.kicad_pcb]
2026-04-19 firmware書き込み手順の修正 #1
